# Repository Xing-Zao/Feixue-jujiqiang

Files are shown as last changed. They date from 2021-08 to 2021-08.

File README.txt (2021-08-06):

00_Priority README ------------- 技术文档，首先阅读
01_Firmware --------------------- 软件相关文件夹
02_Electronics -------------------- 电路相关文件夹
03_Machines --------------------- 机械相关文件夹
04_others ------------------------ 其他文件

README,txt --------------------- 每个分类文件夹都有，含有所处文件夹的阅读索引及必要说明，请最先阅读

相关源文件，软件可能不支持中文路径名，所以请先将项目名称改为中文

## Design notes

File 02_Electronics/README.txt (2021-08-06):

01_source ----------------------------------------- 存放软件源码和已迭代源码

02_tools ------------------------------------------- 程序编写相关软件及使用文档

03_documents ------------------------------------ PCB设计参考文档，含元器件手册

04_others ----------------------------------------- 其他文件

README.txt  -------------------------------------- 每个文件夹下都有该文件，为所处文件夹的阅读索引及必要说明

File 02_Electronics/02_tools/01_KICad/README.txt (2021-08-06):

library——为官方分装库文件及自己制作的封装/3D模型库
KiCad-doc_zh_CN_v0.4——官方文档教程中文版，较老

官方封装库文件是不含3D模型的，完整官方库文件下载：
https://kicad.github.io/footprints/

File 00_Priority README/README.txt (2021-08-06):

01-xx软件 ---- 存放技术文档软件安装包和使用文档。
02-source ---- 存放技术文档源文档（使用 xx软件 编写的文档默认格式）
03-others ---- 存放和技术文档相关的也很重要的文档资料

xxx.pdf为技术文档

技术文档及其他文档都是基于软件 "小书匠" 编写，该软件的免费版可正常使用所有的编辑功能，但无法导出一些特定格式且导出有水印。

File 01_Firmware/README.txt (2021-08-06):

01_source ----------------------------------------- 存放软件源码和已迭代源码

02_tools ------------------------------------------- 程序编写相关软件及使用文档

03_documents ------------------------------------ 软件设计参考文档

04_others ----------------------------------------- 其他文件

README.txt  -------------------------------------- 每个文件夹下都有该文件，为所处文件夹的阅读索引及必要说明

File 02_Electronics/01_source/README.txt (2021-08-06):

01_new_source -------------------------------- 存放最新源码
    |________ Vx.x.x  --------------------  最新版本号（该文件仅存放一个最新版本）
	     |________ 源码名1
	     |________ 源码名2  --------------------  有的工程可能会有同时多个源码

02_old_source --------------------------------- 存放已迭代源码
    |________ Vx.x.x  --------------------  旧版本号
	     |________ 源码名1
	     |________ 源码名2
    |________ Vx.x.x  --------------------  旧版本号
	 ......

有的编程软件可能不支持中文路径，需单独保存到全英文路径在运行

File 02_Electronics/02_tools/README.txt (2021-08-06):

软件文件夹，含有软件安装包及相关安装、使用说明等。

软件可能不支持中文路径，需单独保存到全英文路径在运行

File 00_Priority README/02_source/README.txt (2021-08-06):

该文件夹下存放技术文档的源文档（使用 xx软件 编写的文档默认格式）

如果想要编辑该目录下的文件，请先阅读 “如何编辑技术文档源文件pdf文件”

如果想要阅读该目录下的文件，请转至该文件夹的上级文件夹，阅读其内与该文件夹同名的 .pdf 文件（.pdf为该目录下 .md文档 的导出文件）。

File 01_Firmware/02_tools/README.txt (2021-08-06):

含有各个编程相关软件的安装包及相关安装、使用说明等。

软件可能不支持中文路径，需单独保存到全英文路径在运行

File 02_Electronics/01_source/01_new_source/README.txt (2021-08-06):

文件夹命名规则：xx-文件夹名_Vx.x

有的编程软件可能不支持中文路径，需单独保存到全英文路径在运行

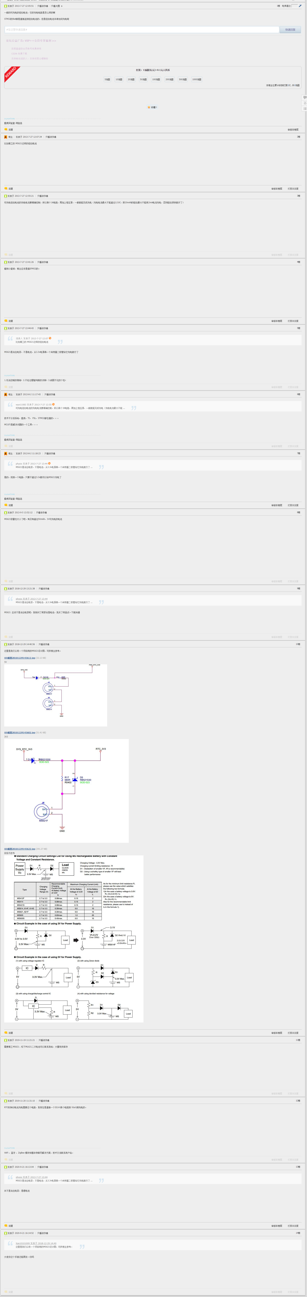
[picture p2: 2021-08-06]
02_Electronics/03_documents/MS621参考电路.png

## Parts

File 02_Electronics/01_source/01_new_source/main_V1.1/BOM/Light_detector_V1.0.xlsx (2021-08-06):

BOM
Reference | Quantity | Value | Footprint | Datasheet/备注 | 采购建议（无任何商业利益）
C1 | 1 | 0.1uF | C_0402_1005Metric | ±5/10% 6.3V/10V/16V
C15 C18 | 2 | 1uF | C_0603_1608Metric | ±5/10% 6.3V/10V/16V
D1 | 1 | SS34F | SMA(DO-214AC) | 见数据表：01_SS34_2019-07-29.PDF | https://item.szlcsc.com/397208.html
IC1 | 1 | STM32G031G6U6 | QFPN28 | 见数据表：02_STM32G031G6U6_2019-09-27.PDF | https://item.szlcsc.com/428998.htmlhttps://item.szlcsc.com/428998.html
J10 | 1 | SERVOB | PinHeader_1x03_P2.54mm_Horizontal | 舵机接口，备用 | https://item.szlcsc.com/54059.html
J5 | 1 | SPK | JST_XH_B2B-XH-A_1x02_P2.50mm_Vertical | 喇叭接口 | https://item.szlcsc.com/442531.html
J6 | 1 | SERVOA | PinHeader_1x03_P2.54mm_Horizontal | 舵机接口 | https://item.szlcsc.com/54059.html
J7 | 1 | UART | JST_XH_B2B-XH-A_1x02_P2.50mm_Vertical | 串口通信接口 | https://item.szlcsc.com/442531.html
J8 J9 | 2 | LEDA | JST_XH_S3B-XH-A-1_1x03_P2.50mm_Horizontal | RGB灯带接口 | https://item.szlcsc.com/442532.html
Q2 | 1 | SS8050 | SOT-23 | 见数据表：03-SS8050Y1200-350.PDF | https://item.szlcsc.com/2507.html
R6 | 1 | 1K | R_0402_1005Metric | ±1% 0.1W_1/16W
SW1 | 1 | MODE_BTN | JST_XH_S2B-XH-A-1_1x02_P2.50mm_Horizontal | 模式键接口 | https://item.szlcsc.com/442531.html
SW2 | 1 | SHOT_BTN | JST_XH_S2B-XH-A-1_1x02_P2.50mm_Horizontal | 射击键接口
U1 | 1 | JQ8900-16P | JQ8900-16P | 语音模块接口 | https://item.szlcsc.com/28187.html
U2 | 1 | XC6206 | SOT-23 | 见数据表：04-XC6206P302MR | https://item.szlcsc.com/5896.html
U6 U7 | 2 | SN74LVC2T45DCUR | VSSOP-8_2.4x2.1mm_P0.5mm | 见数据表：05-SN74LVC2T45DCUR-电平转换_2014-07-11.PDF | https://item.taobao.com/item.htm?spm=a1z09.2.0.0.47aa2e8dxXaam2&id=580985416269&_u=6pkffgddfb8
补充
Reference | Quantity | Value | 采购建议（无任何商业利益）
U1 | 1 | JQ8900-16P | https://item.taobao.com/item.htm?spm=a1z09.2.0.0.47aa2e8dxXaam2&id=588928317675&_u=6pkffgda602
SW1、SW2 | 2 | 限位开关 | https://item.taobao.com/item.htm?spm=a1z0d.6639537.1997196601.766.3add74848Xz0Lt&id=568953039456
J5 | 1 | 喇叭2W 8Ω | https://item.taobao.com/item.htm?spm=a1z09.2.0.0.47aa2e8dxXaam2&id=589167270012&_u=6pkffgdba0d
J8 J9 | 1米 | WS2812灯带 1米60灯 | https://item.taobao.com/item.htm?spm=a1z09.2.0.0.47aa2e8dT9yB5D&id=523924102690&_u=6pkffgdd344
J10 | 1 | MG996舵机 | https://item.taobao.com/item.htm?id=573547711366&ns=1&abbucket=9 (https://item.taobao.com/item.htm?spm=a230r.1.14.1.3f654e40tyc6i0&id=573547711366&ns=1&abbucket=9)

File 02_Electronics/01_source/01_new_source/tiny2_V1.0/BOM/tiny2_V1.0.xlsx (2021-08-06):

BOM
Reference | Quantity | Value | Footprint | Datasheet/备注 | 采购建议（无任何商业利益）
J1 | 1 | Conn_01x06 | JL-6P-4.0PH-5.65H | 数据表：01-弹性连接器.png | https://item.taobao.com/item.htm?spm=a1z09.2.0.0.47aa2e8dxXaam2&id=563475614793&_u=6pkffgd6a19
J2 | 1 | UART | JST_XH_B2B-XH-A_1x02_P2.50mm_Vertical | 串口通信接口 | https://item.szlcsc.com/442531.html

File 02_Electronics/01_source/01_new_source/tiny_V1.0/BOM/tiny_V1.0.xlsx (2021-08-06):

BOM
Reference | Quantity | Value | Footprint | Datasheet/备注 | 采购建议（无任何商业利益）
C1 C3 | 2 | 0.1uF | C_0402_1005Metric | ±5/10% 6.3V/10V/16V
C10 C13 | 2 | 22uF | C_1206_3216Metric | ±5/10% 10V/16V
C15 C18 | 2 | 1uF | C_0603_1608Metric | ±5/10% 6.3V/10V/16V
C2 | 1 | 10nF | C_0402_1005Metric | ±5/10% 6.3V/10V/16V
C8 | 1 | 82pF | C_0402_1005Metric | ±5/10% 6.3V/10V/16V
C9 C24 | 2 | 4.7uF | C_1206_3216Metric | ±5/10% 10V/16V
D5 | 1 | B550C | D_SMC | 见数据表：01_B550C-13-F_2017-10-23.PDF | https://item.szlcsc.com/145771.html
IC1 | 1 | STM32G031G6U6 | UFQFPN28 | 见数据表：02_STM32G031G6U6_2019-09-27.PDF | https://item.szlcsc.com/428998.html
IC3 | 1 | RT8279GSP | Diodes_SO-8EP | 见数据表：03-RT8279GSP-5V_DC-DC_5A-降压_2017-07-12.PDF
J1 | 1 | Conn_01x06 | JL-6P-4.0PH-1.9H | 见数据表：04-弹片连接器.png
J3 | 1 | Conn_01x02 | SM2.54 2P | 电池接插件母壳 | https://item.taobao.com/item.htm?spm=a1z09.2.0.0.47aa2e8dxXaam2&id=522574726866&_u=6pkffgd13ed
J8 J9 | 2 | LEDA | JST_XH_B3B-XH-A_1x03_P2.50mm_Vertical | RGB灯带接口 | https://item.szlcsc.com/442532.html
L2 | 1 | 15uH | SMD,11.5x10x4mm | 见数据表：05-15UH±20%_2017-11-23.PDF | https://item.szlcsc.com/160930.html
R11 | 1 | 31.6k | R_0402_1005Metric | ±1% 0.1W_1/16W
R3 | 1 | 2M | R_0402_1005Metric | ±1% 0.1W_1/16W
R4 R10 | 2 | 100K | R_0402_1005Metric | ±1% 0.1W_1/16W
R5 | 1 | 1M | R_0402_1005Metric | ±1% 0.1W_1/16W
R7 | 1 | 390R | R_0402_1005Metric | ±1% 0.1W_1/16W
U2 | 1 | XC6206 | SOT-23 | 见数据表：06-XC6206P302MR.PDF | https://item.szlcsc.com/5896.html
U6 | 1 | SN74LVC2T45DCUR | VSSOP-8_2.4x2.1mm_P0.5mm | 见数据表：07-SN74LVC2T45DCUR-电平转换_2014-07-11.PDF | https://item.taobao.com/item.htm?spm=a1z09.2.0.0.47aa2e8dxXaam2&id=580985416269&_u=6pkffgddfb8
补充
Reference | Quantity | Value | 采购建议（无任何商业利益）
J8 J9 | 1米 | WS2812灯带 1米120灯 | https://item.taobao.com/item.htm?spm=a1z09.2.0.0.47aa2e8dT9yB5D&id=523924102690&_u=6pkffgdd344
 | 1 | 7.4v锂电池 | https://item.taobao.com/item.htm?id=616409271724&ns=1&abbucket=9 (https://item.taobao.com/item.htm?spm=a230r.1.14.1.74099572KluBTo&id=616409271724&ns=1&abbucket=9)

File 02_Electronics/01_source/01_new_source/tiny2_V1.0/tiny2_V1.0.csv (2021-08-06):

Reference | Quantity | Value | Footprint | Datasheet
D1 D2 D3 D4 D5 D6 | 6 | LED_Small | LED_SMD:LED_0201_0603Metric | ~
H1 H2 | 2 | MountingHole | SamacSys_Parts:MountingHole_1.5x4mm | ~
J1 | 1 | Conn_01x06 | SamacSys_Parts:JL-6P-4.0PH-5.65H | ~
J2 | 1 | UART | Connector_JST:JST_XH_B2B-XH-A_1x02_P2.50mm_Vertical | ~
J3 | 1 | POWER | Connector:JWT_A3963_1x02_P3.96mm_Vertical | ~
J4 | 1 | LED | Connector_JST:JST_XH_B2B-XH-A_1x02_P2.50mm_Vertical | ~
R1 R2 R3 R4 R5 R6 | 6 | R_Small | Resistor_SMD:R_0402_1005Metric | ~

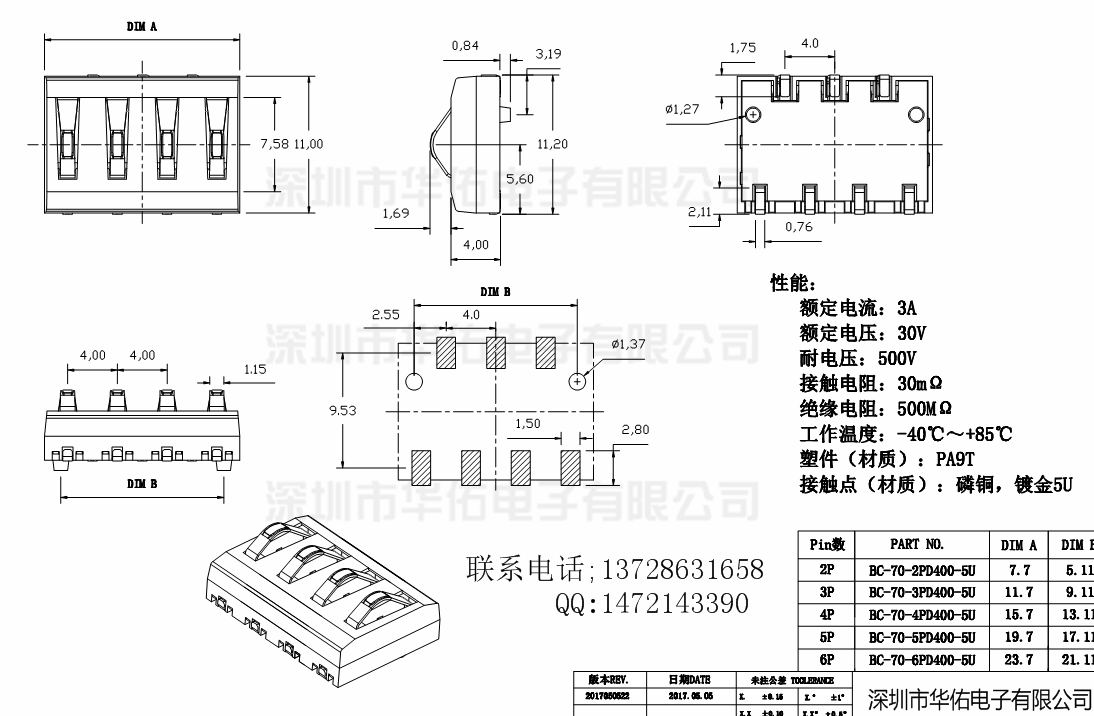
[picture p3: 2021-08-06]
02_Electronics/01_source/01_new_source/tiny2_V1.0/BOM/01-弹性连接器.png

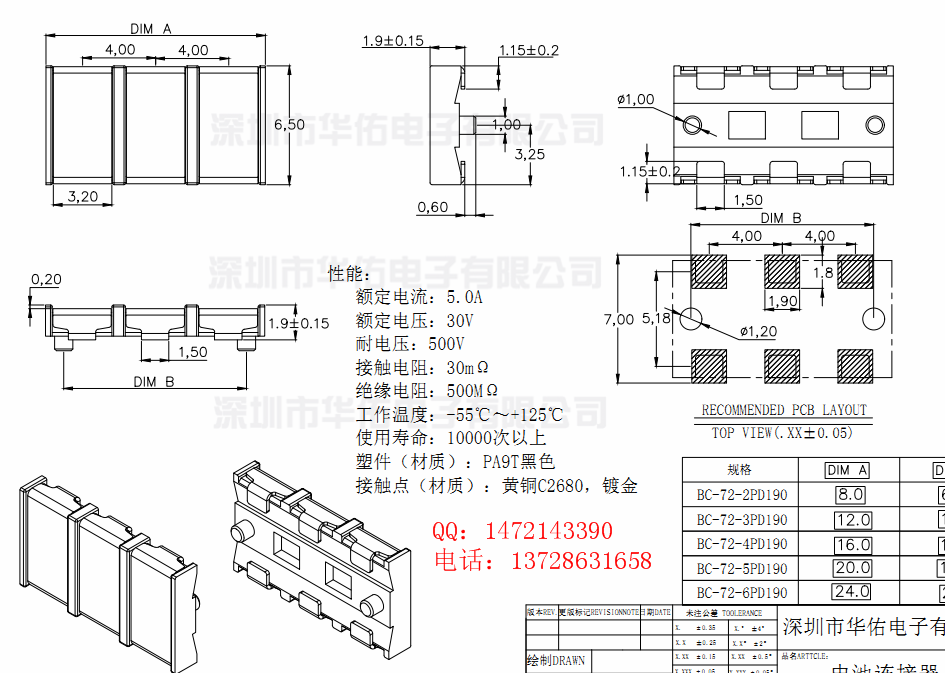
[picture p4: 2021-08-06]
02_Electronics/01_source/01_new_source/tiny_V1.0/BOM/04-弹片连接器.png

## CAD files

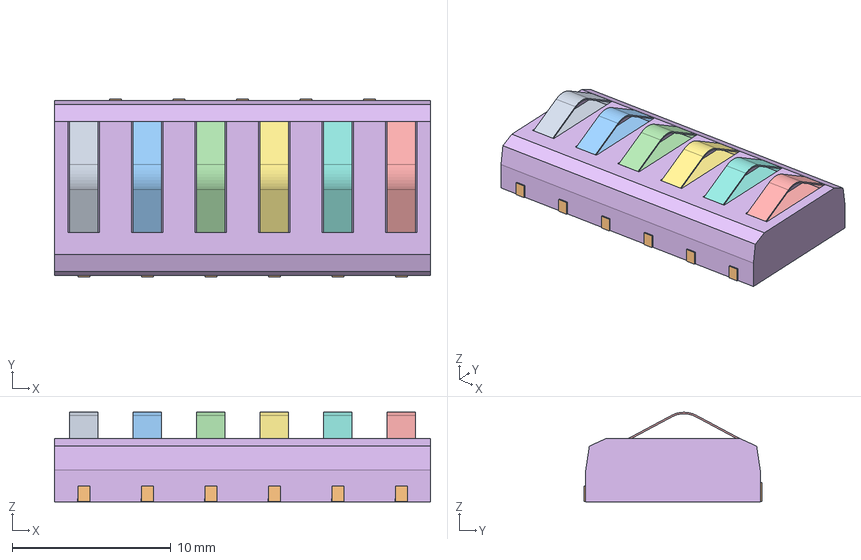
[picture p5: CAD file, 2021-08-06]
02_Electronics/01_source/01_new_source/tiny2_V1.0/3d/JL-6P-4.0PH-5.65H-assembly-A2plus.FCStd
23.7 x 11.2 x 5.65 mm
JL-6P-4.0PH-5.65H-2_003
JL-6P-4.0PH-5.65H-3_001
JL-6P-4.0PH-5.65H-2_002
JL-6P-4.0PH-5.65H-2_004
JL-6P-4.0PH-5.65H-2_005
JL-6P-4.0PH-5.65H-1_001
JL-6P-4.0PH-5.65H-2_001
JL-6P-4.0PH-5.65H-2_006

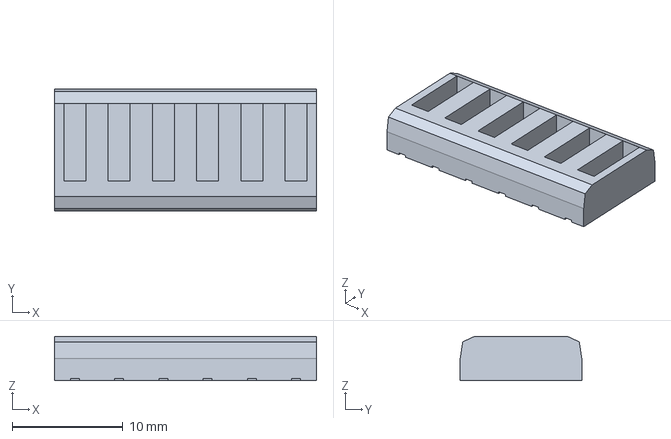
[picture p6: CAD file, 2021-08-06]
02_Electronics/01_source/01_new_source/tiny2_V1.0/3d/JL-6P-4.0PH-5.65H-source_file-kicad.FCStd
23.7 x 11.0 x 4.00 mm

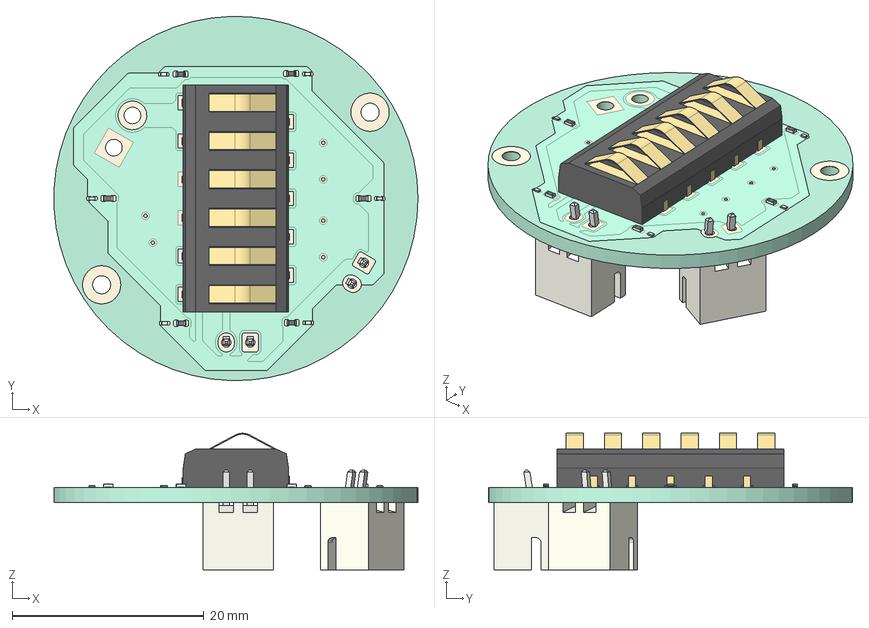
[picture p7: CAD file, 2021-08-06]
02_Electronics/01_source/01_new_source/tiny2_V1.0/3d/接口板-带孔.step
38.0 x 38.0 x 14.3 mm
Pcb_93c3
topTracks_93c3
botTracks_93c3
JL-6P-4.0PH-5.65H-2_003
JL-6P-4.0PH-5.65H-3_001
JL-6P-4.0PH-5.65H-2_002
JL-6P-4.0PH-5.65H-2_004
JL-6P-4.0PH-5.65H-2_005
JL-6P-4.0PH-5.65H-1_001
JL-6P-4.0PH-5.65H-2_001
JL-6P-4.0PH-5.65H-2_006
R6_R_0402_1005Metric_60B28A18 x 6
D6_LED_0201_0603Metric_60B2817D x 6
J4_JST_B2B_XH_A_60B28215 x 2

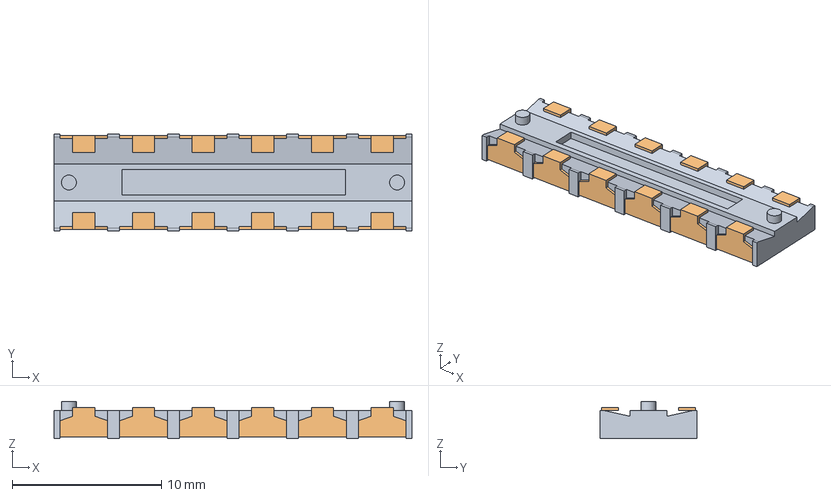
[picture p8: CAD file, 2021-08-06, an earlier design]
02_Electronics/01_source/02_old_source/tiny_V1.0/3d/JL-6P-4.0PH-1.98-assembly-A2plus.FCStd
24.0 x 6.50 x 2.50 mm
JL-6P-4.0PH-1.98-01_001
JL-6P-4.0PH-1.98-02_001

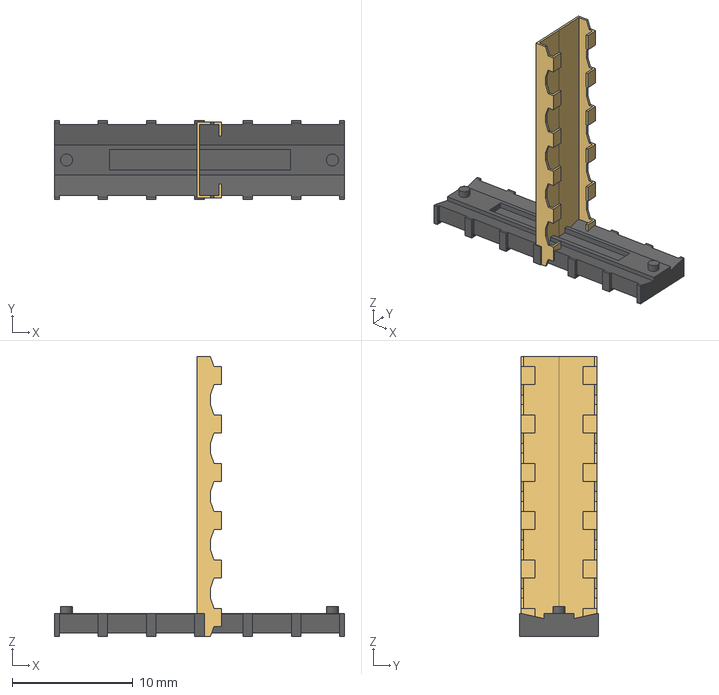
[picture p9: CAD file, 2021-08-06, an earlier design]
02_Electronics/01_source/02_old_source/tiny_V1.0/3d/JL-6P-4.0PH-1.98-source_file-kicad.FCStd
24.0 x 6.50 x 23.2 mm

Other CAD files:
02_Electronics/01_source/01_new_source/tiny2_V1.0/3d/JL-6P-4.0PH-5.65H.step
02_Electronics/01_source/02_old_source/tiny2_V1.0/3d/JL-6P-4.0PH-5.65H.step
02_Electronics/01_source/02_old_source/tiny_V1.0/3d/JL-6P-4.0PH-1.98.step

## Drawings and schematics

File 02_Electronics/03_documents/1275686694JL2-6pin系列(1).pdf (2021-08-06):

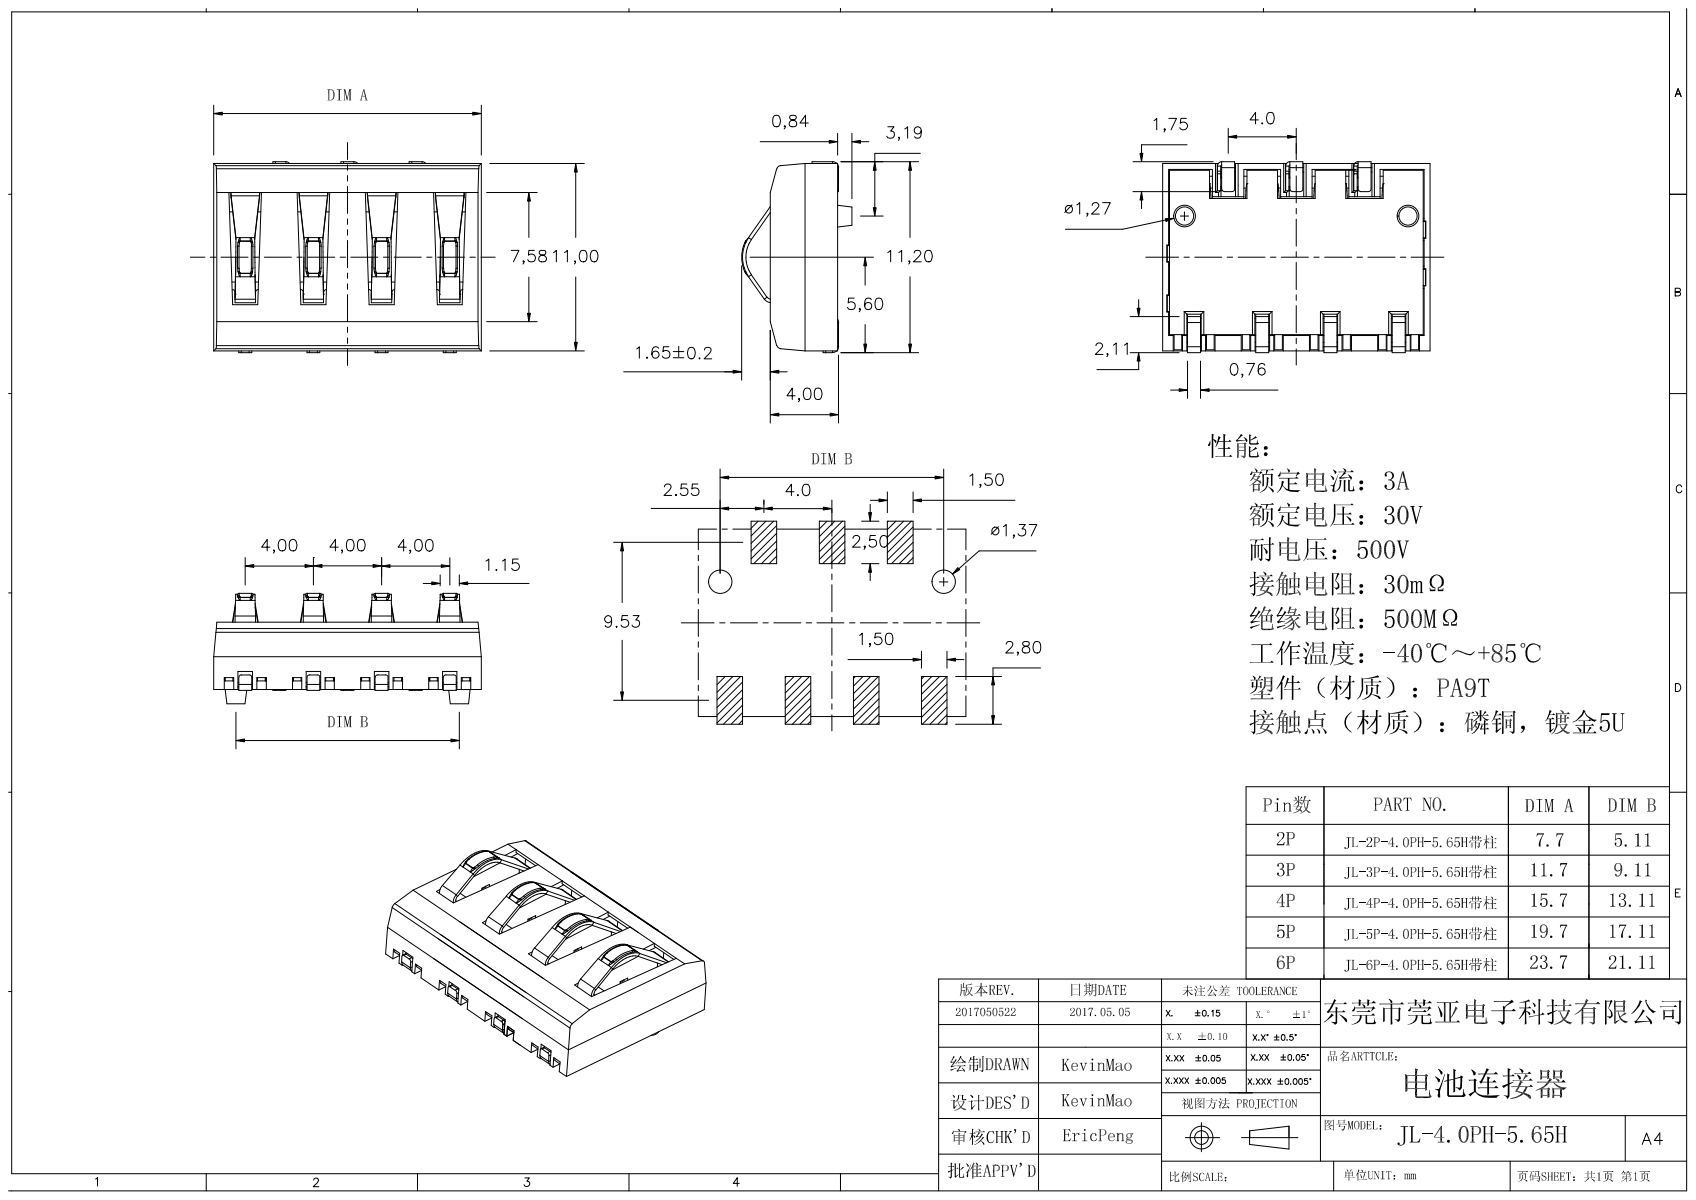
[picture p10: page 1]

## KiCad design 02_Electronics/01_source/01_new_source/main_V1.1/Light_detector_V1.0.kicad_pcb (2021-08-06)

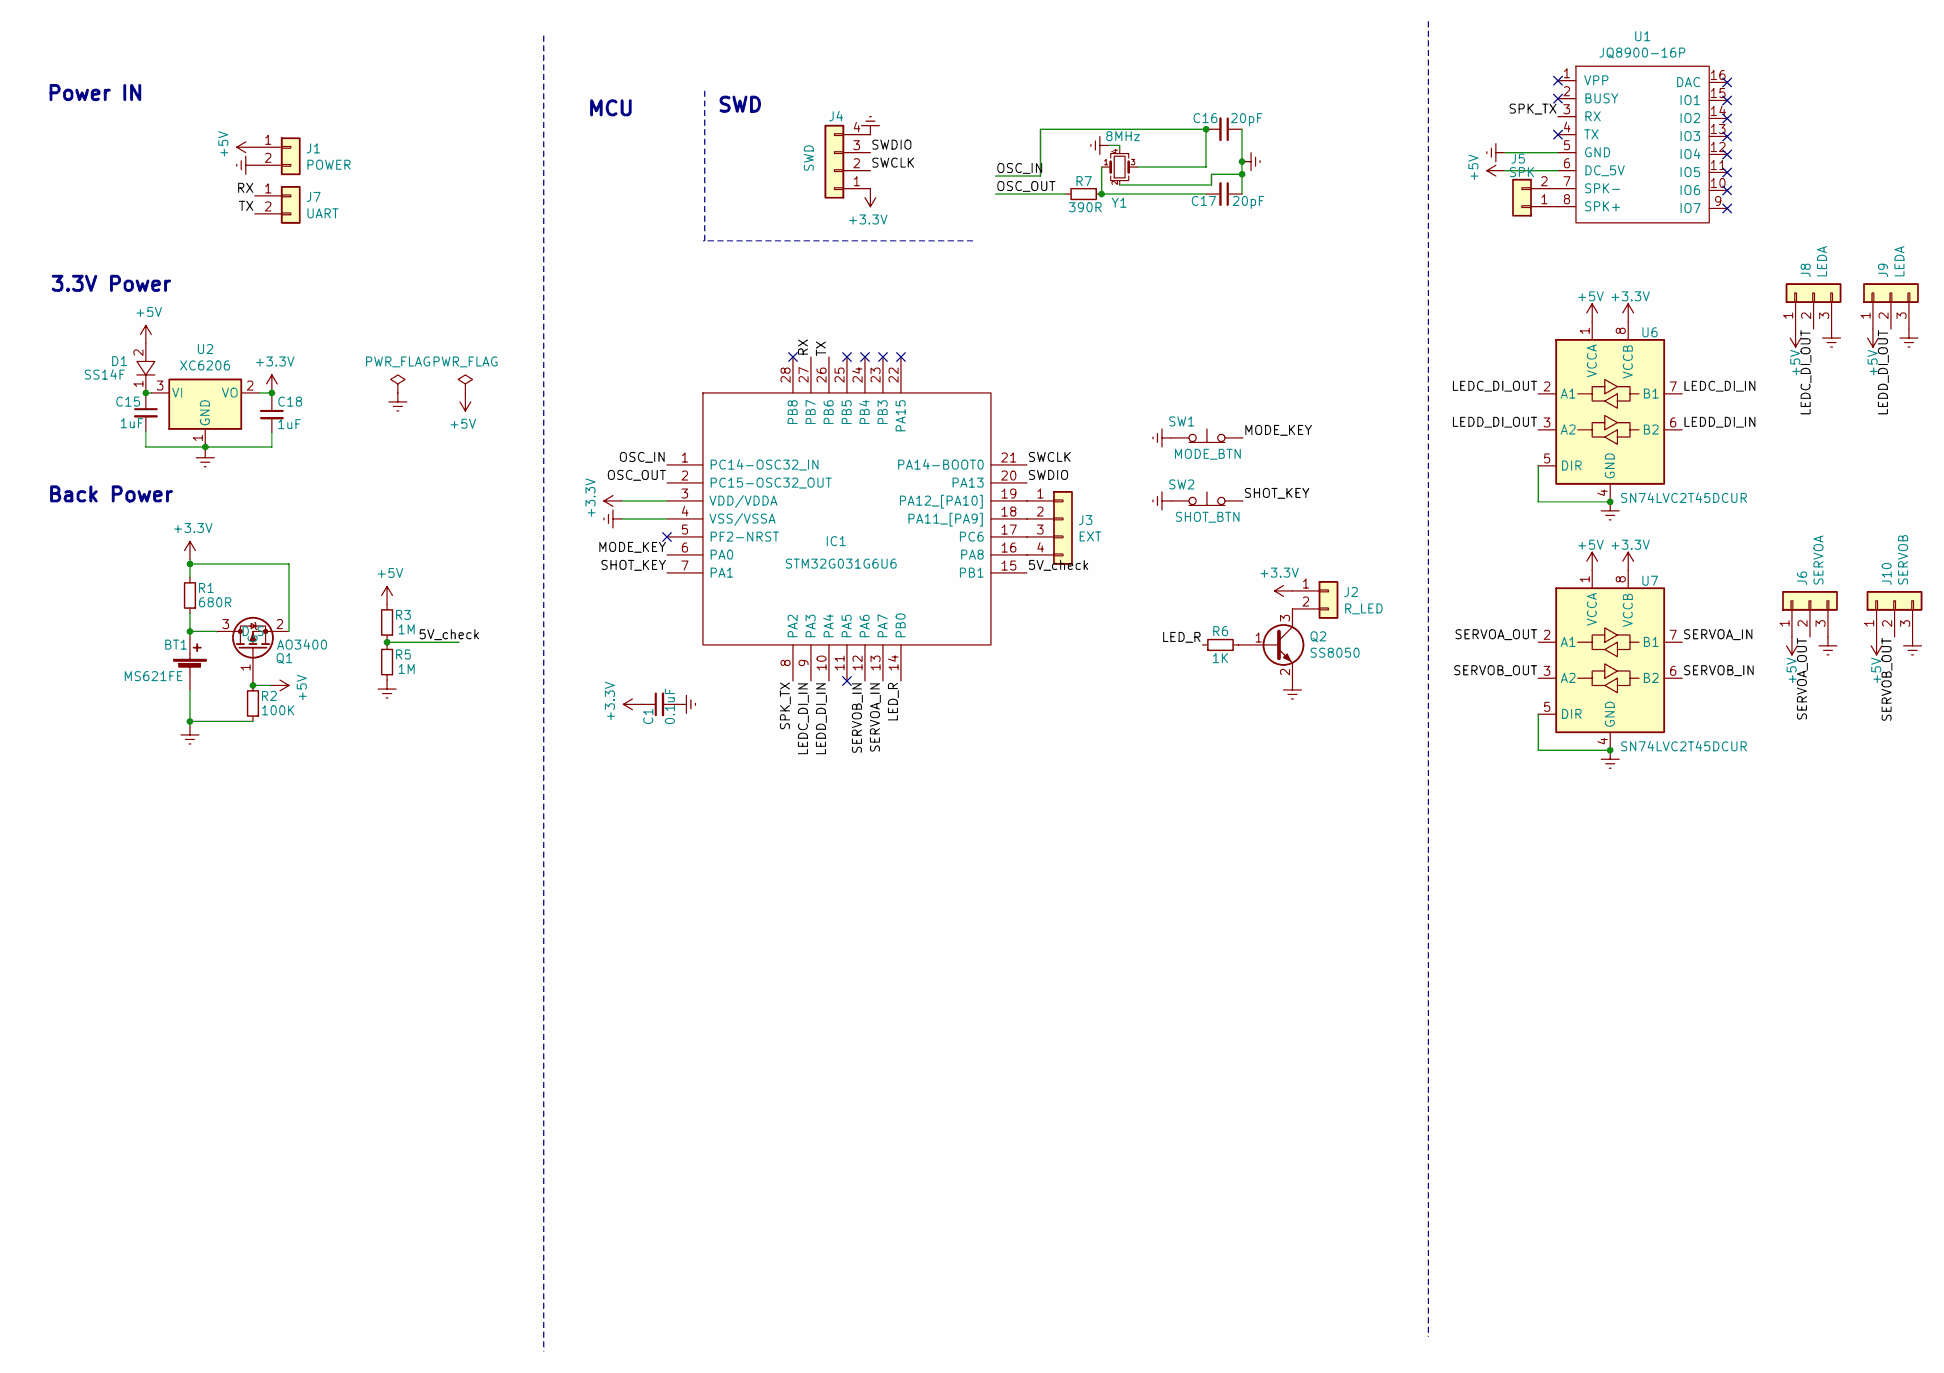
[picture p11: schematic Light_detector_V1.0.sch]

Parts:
BT1: MS621FE; BatteryHolder_Seiko_MS621F
C1: 0.1uF; C_0402_1005Metric
C15, C18: 1uF; C_0603_1608Metric
C16, C17: 20pF; C_0402_1005Metric
D1: SS14F; D_SOD-123F; Manufacturer_Part_Number SS34A
IC1: STM32G031G6U6; UFQFPN28; Manufacturer_Part_Number STM32G031G6U6; Mouser Part Number 511-STM32G031G6U6
J1: POWER; JWT_A3963_1x02_P3.96mm_Vertical
J2: R_LED; JST_XH_S2B-XH-A-1_1x02_P2.50mm_Horizontal
J3: EXT; PinHeader_1x04_P2.00mm_Vertical
J4: SWD; PinHeader_1x04_P1.27mm_Vertical
J5: SPK; JST_XH_B2B-XH-A_1x02_P2.50mm_Vertical
J6: SERVOA; PinHeader_1x03_P2.54mm_Horizontal
J7: UART; JST_XH_B2B-XH-A_1x02_P2.50mm_Vertical
J8, J9: LEDA; JST_XH_S3B-XH-A-1_1x03_P2.50mm_Horizontal
J10: SERVOB; PinHeader_1x03_P2.54mm_Horizontal
Q1: AO3400; SOT-23; Manufacturer_Part_Number IRLML6401TRPBF
Q2: SS8050; SOT-23
R1: 680R; R_0402_1005Metric
R2: 100K; R_0402_1005Metric
R3, R5: 1M; R_0402_1005Metric
R6: 1K; R_0402_1005Metric
R7: 390R; R_0402_1005Metric
SW1: MODE_BTN; JST_XH_S2B-XH-A-1_1x02_P2.50mm_Horizontal
SW2: SHOT_BTN; JST_XH_S2B-XH-A-1_1x02_P2.50mm_Horizontal
U1: JQ8900-16P
U2: XC6206; SOT-23
U6, U7: SN74LVC2T45DCUR; VSSOP-8_2.4x2.1mm_P0.5mm
Y1: 8MHz; Crystal_SMD_3225-4Pin_3.2x2.5mm

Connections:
+3V3: C1.1, C18.1, IC1.3 (VDD/VDDA), J2.1, J4.1, Q1.2 (S), R1.2, U2.2 (VO), U6.8 (VCCB), U7.8 (VCCB)
+5V: D1.2, J1.1, J6.1, J8.1, J9.1, J10.1, Q1.1 (G), R2.2, R3.2, U1.6 (DC_5V), U6.1 (VCCA), U7.1 (VCCA)
/5V_check: IC1.15 (PB1), R3.1, R5.2
/LEDC_DI_IN: IC1.9 (PA3), U6.7 (B1)
/LEDC_DI_OUT: J8.2, U6.2 (A1)
/LEDD_DI_IN: IC1.10 (PA4), U6.6 (B2)
/LEDD_DI_OUT: J9.2, U6.3 (A2)
/LED_R: IC1.14 (PB0), R6.1
/MODE_KEY: IC1.6 (PA0), SW1.2 (B)
/OSC_IN: C16.2, IC1.1 (PC14-OSC32_IN), Y1.3
/OSC_OUT: IC1.2 (PC15-OSC32_OUT), R7.2
/RX: IC1.27 (PB7), J7.1
/SERVOA_IN: IC1.13 (PA7), U7.7 (B1)
/SERVOA_OUT: J6.2, U7.2 (A1)
/SERVOB_IN: IC1.12 (PA6), U7.6 (B2)
/SERVOB_OUT: J10.2, U7.3 (A2)
/SHOT_KEY: IC1.7 (PA1), SW2.2 (B)
/SPK_TX: IC1.8 (PA2), U1.3 (RX)
/SWCLK: IC1.21 (PA14-BOOT0), J4.2
/SWDIO: IC1.20 (PA13), J4.3
/TX: IC1.26 (PB6), J7.2
Earth: BT1.2 (-), C1.2, C15.2, C16.1, C17.1, C18.2, IC1.4 (VSS/VSSA), J1.2, J4.4, J6.3, J8.3, J9.3, J10.3, Q2.2 (E), R2.1, R5.1, SW1.1 (A), SW2.1 (A), U1.5 (GND), U2.1 (GND), U6.4 (GND), U6.5 (DIR), U7.4 (GND), U7.5 (DIR), Y1.2, Y1.4
unnamed: BT1.1 (+), Q1.3 (D), R1.1
unnamed: C15.1, D1.1, U2.3 (VI)
unnamed: C17.2, R7.1, Y1.1
unnamed: IC1.16 (PA8), J3.4
unnamed: IC1.17 (PC6), J3.3
unnamed: IC1.18 (PA11_[PA9]), J3.2
unnamed: IC1.19 (PA12_[PA10]), J3.1
unnamed: J2.2, Q2.3 (C)
unnamed: J5.1, U1.8 (SPK+)
unnamed: J5.2, U1.7 (SPK-)
unnamed: Q2.1 (B), R6.2

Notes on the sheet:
Power IN
SWD
MCU
Back Power
3.3V Power

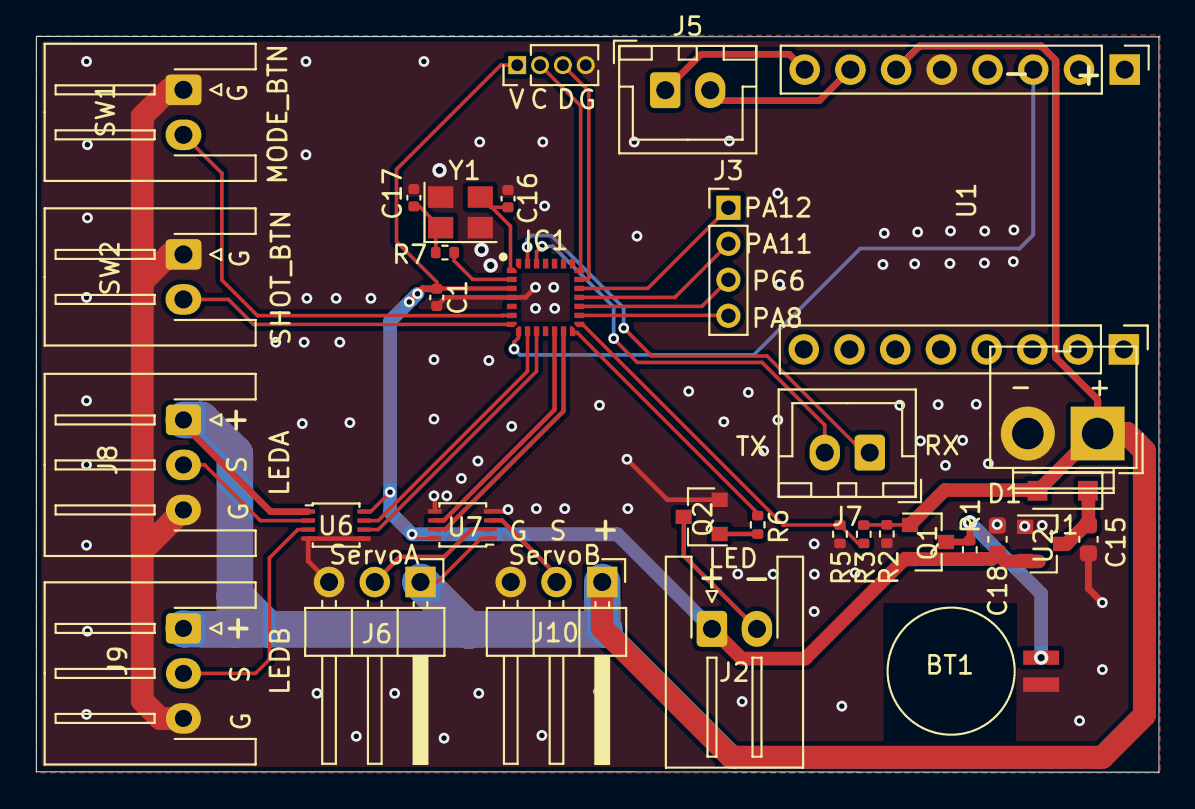
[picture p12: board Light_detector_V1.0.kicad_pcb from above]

Board: 2 copper layers, 62.4 x 40.9 mm, 33 parts (0 on the bottom side), 33 nets.

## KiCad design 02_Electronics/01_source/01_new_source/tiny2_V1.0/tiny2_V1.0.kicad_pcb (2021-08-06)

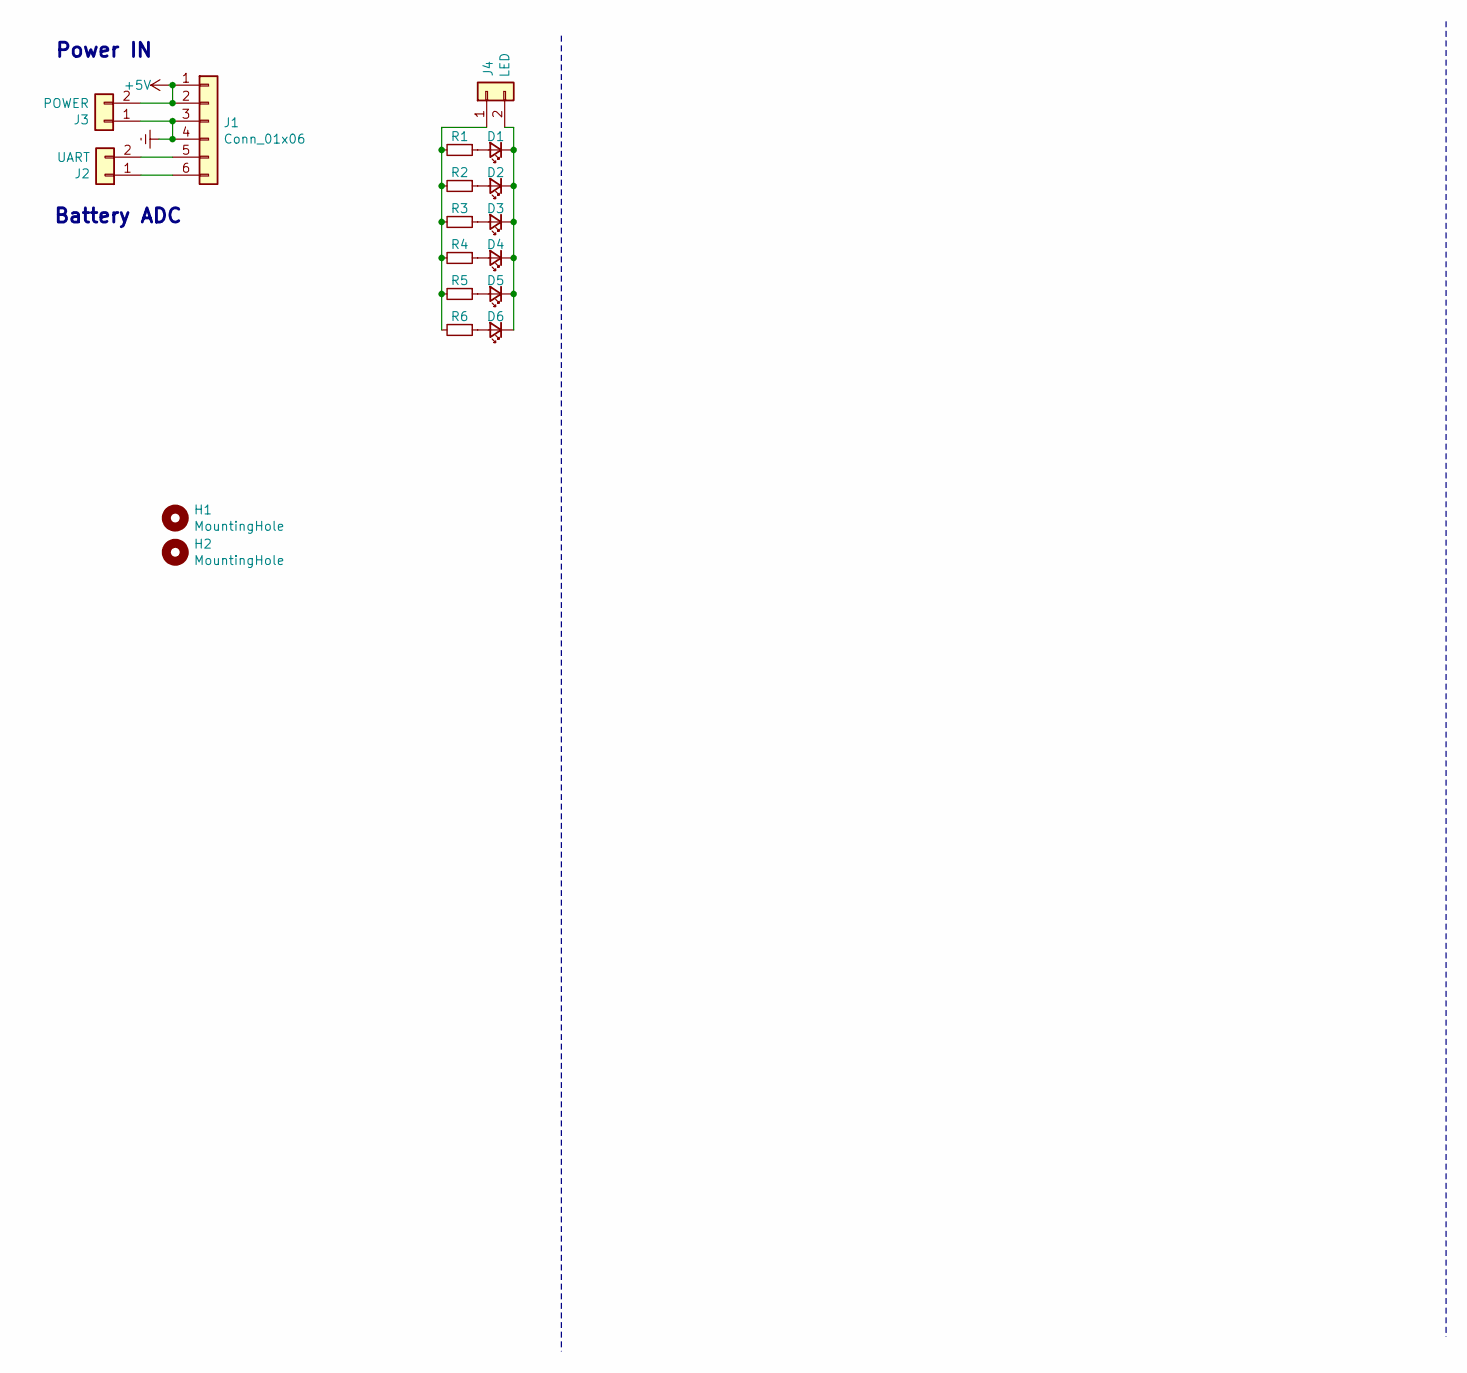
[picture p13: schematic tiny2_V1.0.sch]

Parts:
D1, D2, D3, D4, D5, D6: LED_Small; LED_0201_0603Metric
H1, H2: MountingHole; MountingHole_1.5x4mm
J1: Conn_01x06; JL-6P-4.0PH-5.65H
J2: UART; JST_XH_B2B-XH-A_1x02_P2.50mm_Vertical
J3: POWER; JWT_A3963_1x02_P3.96mm_Vertical
J4: LED; JST_XH_B2B-XH-A_1x02_P2.50mm_Vertical
R1, R2, R3, R4, R5, R6: R_Small; R_0402_1005Metric

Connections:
+5V: J1.1, J1.2, J3.2
Earth: J1.3, J1.4, J3.1
unnamed: D1.1 (K), D2.1 (K), D3.1 (K), D4.1 (K), D5.1 (K), D6.1 (K), J4.2
unnamed: D1.2 (A), R1.1
unnamed: D2.2 (A), R2.1
unnamed: D3.2 (A), R3.1
unnamed: D4.2 (A), R4.1
unnamed: D5.2 (A), R5.1
unnamed: D6.2 (A), R6.1
unnamed: J1.5, J2.2
unnamed: J1.6, J2.1
unnamed: J4.1, R1.2, R2.2, R3.2, R4.2, R5.2, R6.2

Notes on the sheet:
Power IN
Battery ADC

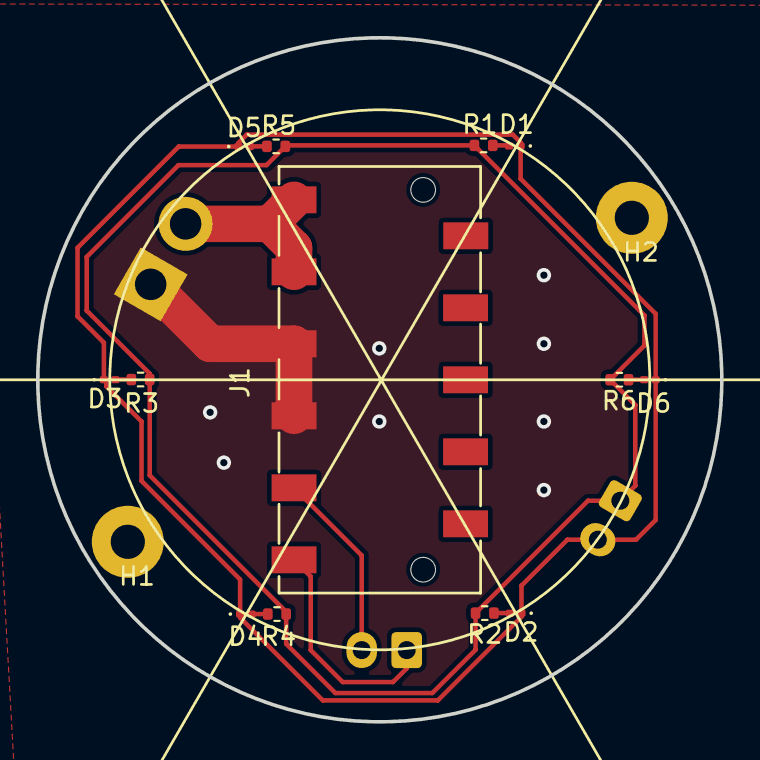
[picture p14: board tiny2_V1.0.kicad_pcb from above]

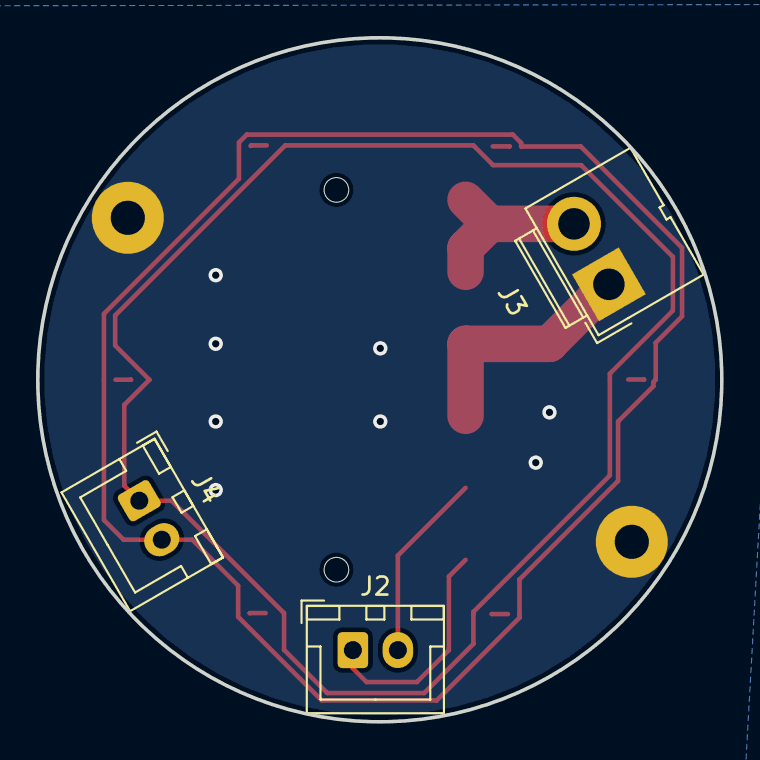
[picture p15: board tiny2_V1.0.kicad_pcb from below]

Board: 2 copper layers, 38.0 x 38.0 mm, 18 parts (3 on the bottom side), 12 nets.

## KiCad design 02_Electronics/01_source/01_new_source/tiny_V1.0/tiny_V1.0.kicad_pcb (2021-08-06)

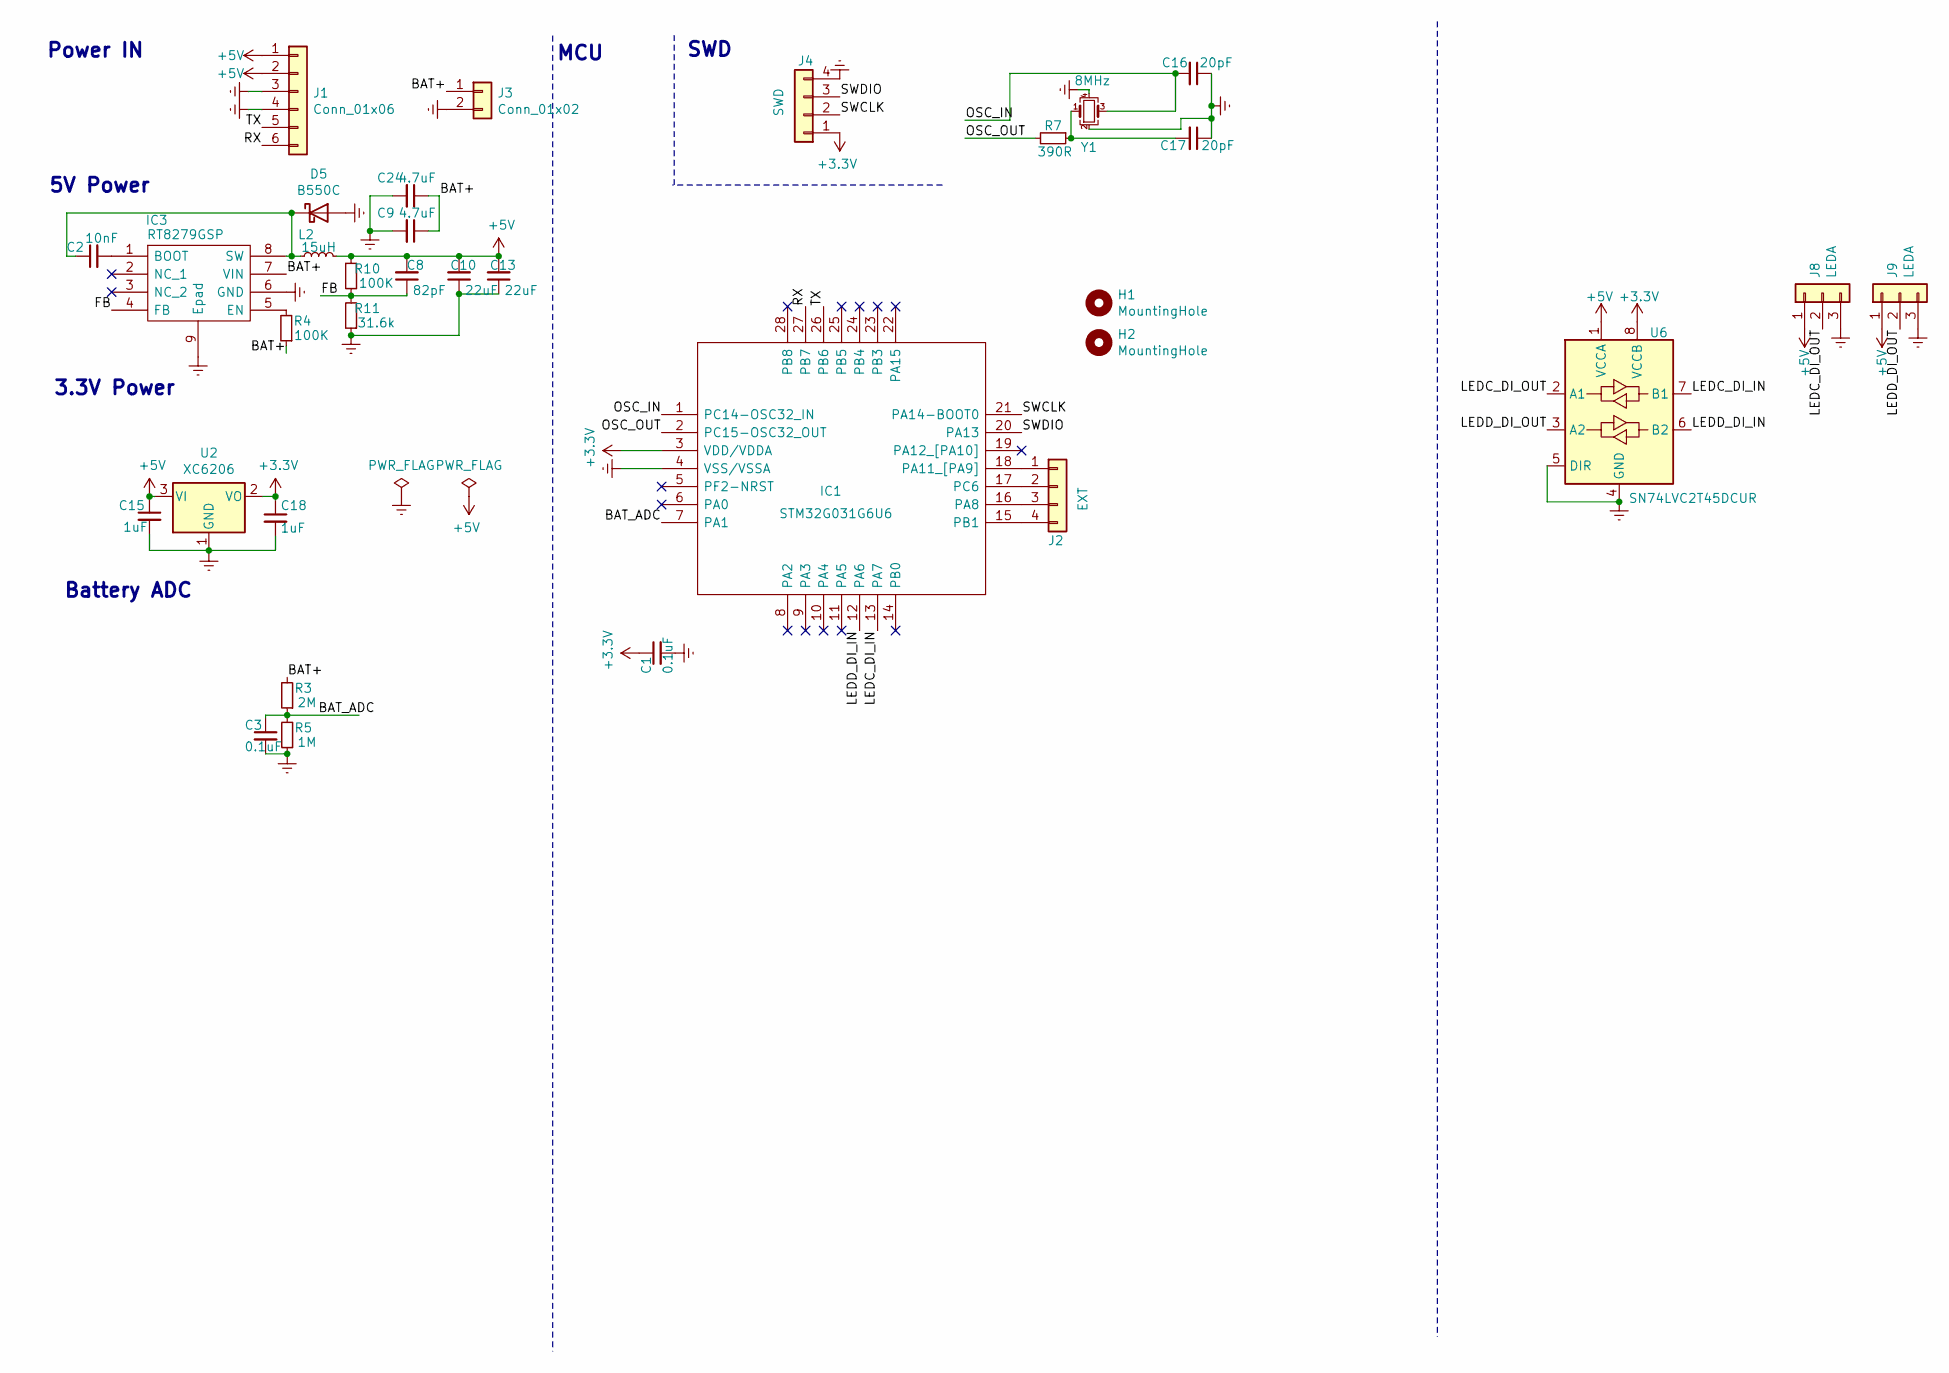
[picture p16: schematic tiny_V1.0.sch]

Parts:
C1, C3: 0.1uF; C_0402_1005Metric
C2: 10nF; C_0402_1005Metric
C8: 82pF; C_0402_1005Metric
C9, C24: 4.7uF; C_1206_3216Metric
C10, C13: 22uF; C_1206_3216Metric
C15, C18: 1uF; C_0603_1608Metric
C16, C17: 20pF; C_0402_1005Metric
D5: B550C; D_SMC
H1, H2: MountingHole; MountingHole_1.5x4mm
IC1: STM32G031G6U6; UFQFPN28; Manufacturer_Part_Number STM32G031G6U6; Mouser Part Number 511-STM32G031G6U6
IC3: RT8279GSP; Diodes_SO-8EP; Manufacturer_Part_Number RT8279GSP
J1: Conn_01x06; JL-6P-4.0PH-1.9H
J2: EXT; PinHeader_1x04_P2.00mm_Vertical
J3: Conn_01x02; JWT_A3963_1x02_P3.96mm_Vertical
J4: SWD; PinHeader_1x04_P1.27mm_Vertical
J8, J9: LEDA; JST_XH_B3B-XH-A_1x03_P2.50mm_Vertical
L2: 15uH; L_Neosid_SM-PIC1004H
R3: 2M; R_0402_1005Metric
R4, R10: 100K; R_0402_1005Metric
R5: 1M; R_0402_1005Metric
R7: 390R; R_0402_1005Metric
R11: 31.6k; R_0402_1005Metric
U2: XC6206; SOT-23
U6: SN74LVC2T45DCUR; VSSOP-8_2.4x2.1mm_P0.5mm
Y1: 8MHz; Crystal_SMD_3225-4Pin_3.2x2.5mm

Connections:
+3V3: C1.1, C18.1, IC1.3 (VDD/VDDA), J4.1, U2.2 (VO), U6.8 (VCCB)
+5V: C8.2, C10.2, C13.2, C15.1, J1.1, J1.2, J8.1, J9.1, L2.2, R10.2, U2.3 (VI), U6.1 (VCCA)
/BAT+: C9.1, C24.1, IC3.7 (VIN), J3.1, R3.2, R4.1
/BAT_ADC: C3.1, IC1.7 (PA1), R3.1, R5.2
/FB: C8.1, IC3.4 (FB), R10.1, R11.2
/LEDC_DI_IN: IC1.13 (PA7), U6.7 (B1)
/LEDC_DI_OUT: J8.2, U6.2 (A1)
/LEDD_DI_IN: IC1.12 (PA6), U6.6 (B2)
/LEDD_DI_OUT: J9.2, U6.3 (A2)
/OSC_IN: C16.2, IC1.1 (PC14-OSC32_IN), Y1.3
/OSC_OUT: IC1.2 (PC15-OSC32_OUT), R7.2
/RX: IC1.27 (PB7), J1.6
/SWCLK: IC1.21 (PA14-BOOT0), J4.2
/SWDIO: IC1.20 (PA13), J4.3
/TX: IC1.26 (PB6), J1.5
Earth: C1.2, C3.2, C9.2, C10.1, C13.1, C15.2, C16.1, C17.1, C18.2, C24.2, D5.2 (A), IC1.4 (VSS/VSSA), IC3.6 (GND), IC3.9 (Epad), J1.3, J1.4, J3.2, J4.4, J8.3, J9.3, R5.1, R11.1, U2.1 (GND), U6.4 (GND), U6.5 (DIR), Y1.2, Y1.4
unnamed: C2.1, D5.1 (K), IC3.8 (SW), L2.1
unnamed: C2.2, IC3.1 (BOOT)
unnamed: C17.2, R7.1, Y1.1
unnamed: IC1.15 (PB1), J2.4
unnamed: IC1.16 (PA8), J2.3
unnamed: IC1.17 (PC6), J2.2
unnamed: IC1.18 (PA11_[PA9]), J2.1
unnamed: IC3.5 (EN), R4.2

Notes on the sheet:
3.3V Power
MCU
SWD
5V Power
Power IN
Battery ADC

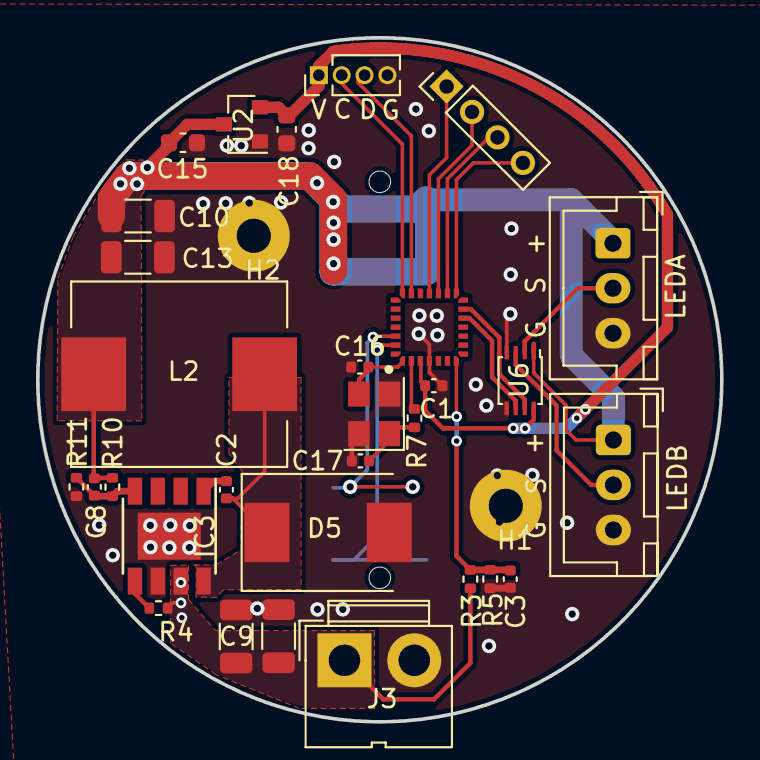
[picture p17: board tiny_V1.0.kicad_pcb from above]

Board: 2 copper layers, 38.0 x 38.0 mm, 33 parts (1 on the bottom side), 24 nets.

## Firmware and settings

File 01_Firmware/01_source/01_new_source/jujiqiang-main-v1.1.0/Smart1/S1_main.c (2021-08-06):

/**
  *   飞雪狙击枪 Firmware
 * Copyright (c) 2020-2021 LonlyPan. All rights reserved.
 *
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
 */
/*
 * @file         : S1_main.c
 * @author       : LonlyPan
 * @version      : V0.0.0
 * @date         : 2021-06-07 11:35
 * @brief        : 主函数
 * @attention    : // 注意事项
 * @Modification : 初始版本
 * @LastEditTime : 2021-06-08 09:34
 * @History      :
 *   1.Version:
 *     Author:
 *     date:
 *     Modification:
 *   2.Version:
 *     ......
 */

#include "S1_main.h"
#include "tim.h"
#include "ws2812.h"
#include "servo.h"
#include "key.h"
#include "usart.h"
#include "uart.h"
#include "stdio.h"

static uint8_t shot_status = SHOT_BLUE; // 默认蓝色
// AA - 指 令 类 型 - 数 据 长 度 （ n ） - 数 据 1 － 数 据 n － 和 检 验 ( S M )
// 制定曲目： AA 07 02 曲目高  曲目低  SM
// 音量设置： AA 13 01 VOL（0-30） SM
// 数组最后一个元素为 之 前 所 有 字 节 之 和 的 低 8 位 , 即 起 始 码 到 数 据 相 加 后 取 低 8 位
uint8_t Buffer1[6] = {0xAA,0x07,0x02,0x00,0x01,0xB4};  // 射击声
uint8_t Buffer2[6] = {0xAA,0x07,0x02,0x00,0x02,0xB5};  // 没电声
uint8_t Buffer3[5] = {0xAA, 0x13, 0x01, 0x1E, 0xDC};   // 设置音量最大


/**
 * @brief: 按键处理函数
 * @note:  切换四次状态
 * @detail: key_value 状态不会保持保存
 */
void key_process(void)
{
	uint8_t mode_key_value =mode_button_tick();
	uint8_t shot_key_value =shot_button_tick();
    if(mode_key_value == SINGLE_CLICK){
    	if(shot_status == SHOT_BLUE){  // 橙色射击模式
    		printf("1\r\n");
    		shot_status = SHOT_ORG;
    	}
    	else if(shot_status == SHOT_ORG){   // 蓝色常量
    		printf("2\r\n");
    		ws2812_blu_style();
    	    shot_status = NO_BLU;
    	 }
    	else if(shot_status == NO_BLU){   // 橙色常量
    		printf("3\r\n");
    		ws2812_org_style();
    	    shot_status = NO_ORG;
    	}

    	else if(shot_status == NO_ORG){   // 蓝色射击模式
    		ws281x_close_all();
    		printf("0\r\n");
    	    shot_status = SHOT_BLUE;
    	 }
    }
    if(shot_key_value == SINGLE_CLICK){  // 射击

        if(shot_status == NO_BLU || shot_status == NO_ORG){  // 射击
    		// 发送没电测试信号
        	printf("8\r\n");

    		servo_set_angle(CLOSE_ANGLE);
    		ws281x_close_all();
    		HAL_UART_Transmit(&huart2,&Buffer2,6,1000);  // 语音

    		HAL_Delay(2000);
    	    shot_status = SHOT_BLUE;
        }

        else if(shot_status == SHOT_BLUE|| shot_status == SHOT_ORG){
			servo_set_angle(OPEN_ANGLE);
			HAL_UART_Transmit(&huart2,&Buffer1,6,1000);  // 发送10个数据
			if(shot_status == SHOT_BLUE){
				ws2812_shot_blu_style();
				HAL_Delay(300);
			}
			else if(shot_status == SHOT_ORG){
				ws2812_shot_org_style();
				HAL_Delay(200);
			}
			servo_set_angle(CLOSE_ANGLE);
        }
    }
}

/**
 * @brief  标准闲置程序使机器保持活动状态
 */

void idle(){
	if(USART_RX_STA&0x8000){
		if(USART_RX_BUF[0] == '9'){
			servo_set_angle(CLOSE_ANGLE);
			ws281x_close_all();
			HAL_UART_Transmit(&huart2,&Buffer2,6,1000);  // 发送10个数据
			while(1);
		}
		USART_RX_STA=0;
	}
}


/**
 * @brief  定时器初始化
 *         PWM初始化
  *                开机检测
 */
void setup(void)
{
	uart_init();

	ws281x_init();

	servo_init();   /* 舵机初始化 */

	ws2812_shot_blu_style();
	//HAL_UART_Transmit(&huart2,&Buffer3,5,1000);  // 发送10个数据
 	HAL_Delay(1000);

}

void loop(void)
{
	idle();

	key_process();

}

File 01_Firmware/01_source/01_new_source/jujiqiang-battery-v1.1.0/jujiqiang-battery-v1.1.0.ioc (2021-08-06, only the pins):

Mcu.UserName=STM32G031G8Ux
PA13.Signal=SYS_SWDIO
PB6.Signal=USART1_TX
PA1.Signal=ADC1_IN1
PA14-BOOT0.Signal=SYS_SWCLK
PB7.Signal=USART1_RX
PA7.Signal=S_TIM3_CH2

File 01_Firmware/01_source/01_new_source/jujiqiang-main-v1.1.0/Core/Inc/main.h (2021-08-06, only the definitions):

#define MODE_KEY_Pin GPIO_PIN_0
#define MODE_KEY_GPIO_Port GPIOA
#define SHOT_KEY_Pin GPIO_PIN_1
#define SHOT_KEY_GPIO_Port GPIOA
#define TEST_Pin GPIO_PIN_11
#define TEST_GPIO_Port GPIOA

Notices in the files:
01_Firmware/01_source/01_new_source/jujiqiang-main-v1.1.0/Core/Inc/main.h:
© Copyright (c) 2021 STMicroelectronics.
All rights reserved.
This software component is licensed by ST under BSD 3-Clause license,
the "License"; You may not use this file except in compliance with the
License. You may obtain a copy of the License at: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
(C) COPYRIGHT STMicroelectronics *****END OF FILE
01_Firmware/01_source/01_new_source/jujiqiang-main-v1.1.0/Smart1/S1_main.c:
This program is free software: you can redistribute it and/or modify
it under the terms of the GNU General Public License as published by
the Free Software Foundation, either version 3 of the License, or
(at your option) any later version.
